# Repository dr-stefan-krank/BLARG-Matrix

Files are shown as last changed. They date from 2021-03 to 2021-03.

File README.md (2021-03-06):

**BLARG-Matrix is an open analog audio matrix board to be integrated in smart home applications.**

Its purpose is to build a central multi-room audio system.
For example 4 players connected to 8 rooms in stereo mode, 8 players to 16 rooms in mono configuration or anything in between.

**Features**

- 8x16 matrix chip to route any input to one or more outputs.
- All outputs are digitally volume controlled.
- 11 unused GPIO of the ESP
- A 16 GPIO IO expander allows for control of a 16 channel relais board for switching amplifiers.
- All inputs and outputs are unbalanced line level.

Note: The board has to be equipped with a standard ESP32-DEVKIT-C.

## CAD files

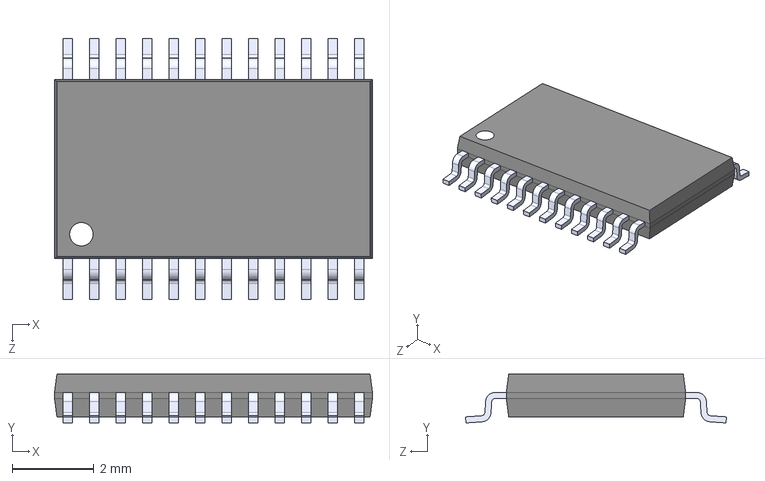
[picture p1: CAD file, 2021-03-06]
components/TCA6416APWR/TCA6416APWR.step
7.80 x 1.20 x 6.40 mm

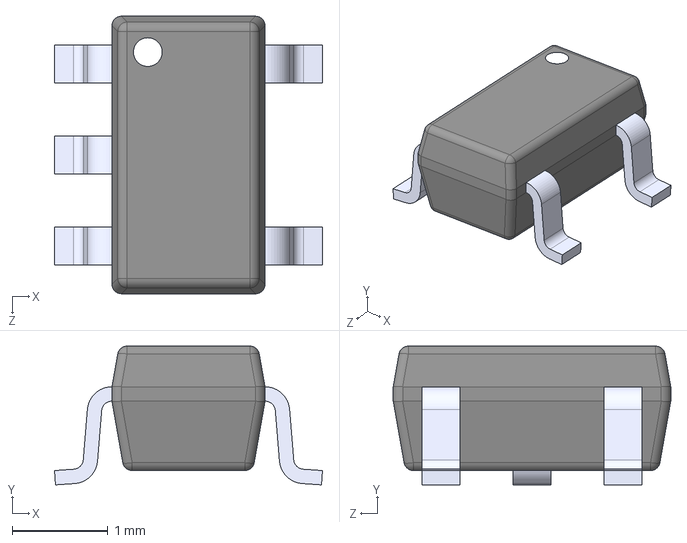
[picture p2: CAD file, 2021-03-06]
components/TPS60403DBVR/TPS60403DBVR.step
2.80 x 1.45 x 2.90 mm

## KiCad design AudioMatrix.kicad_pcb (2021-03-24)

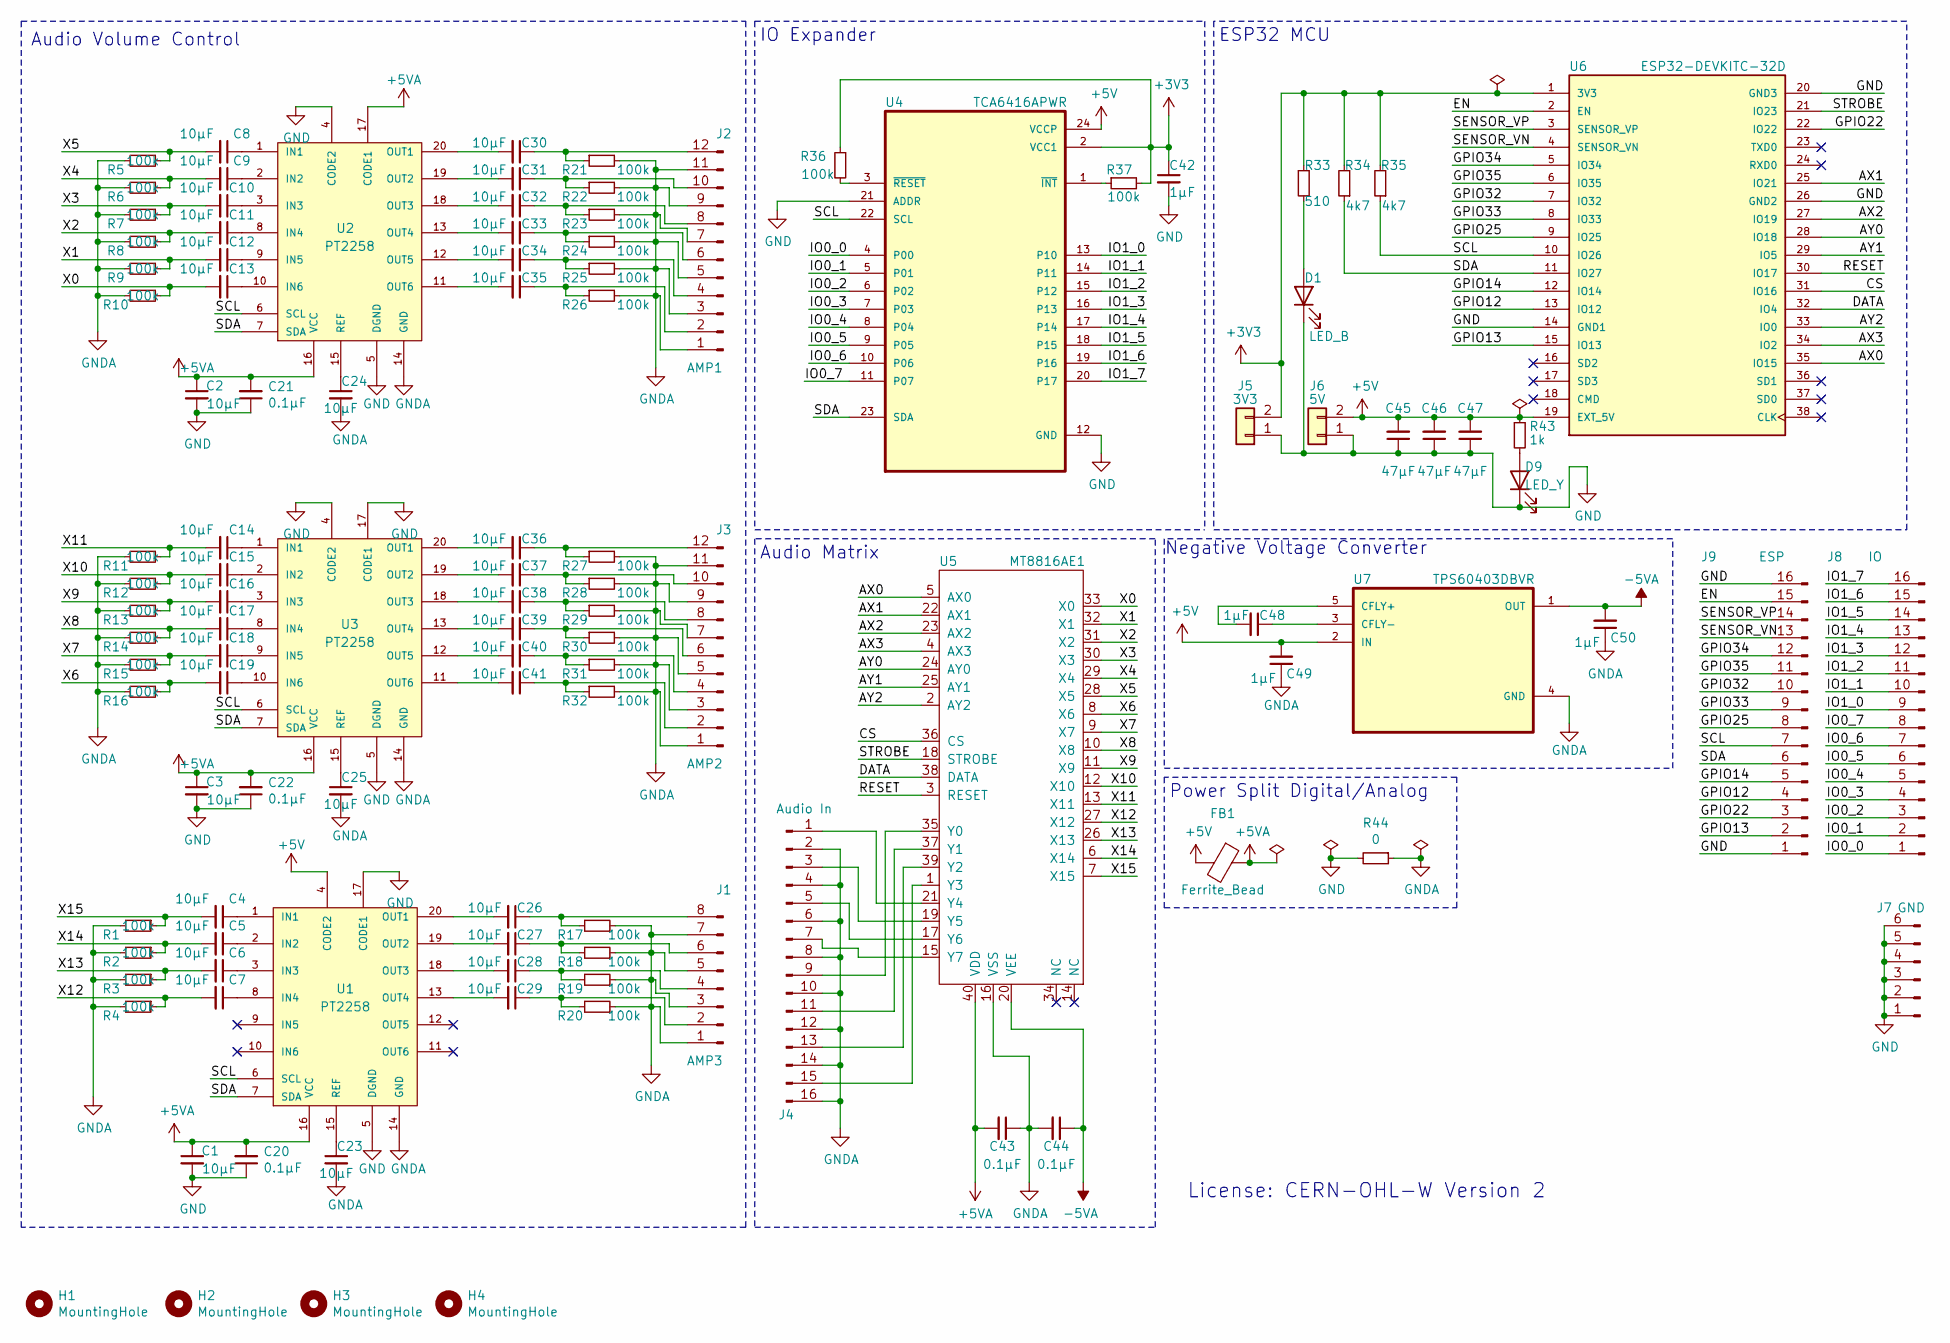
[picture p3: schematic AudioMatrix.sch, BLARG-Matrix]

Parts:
C1, C2, C3, C4, C5, C6, C7, C8, C9, C10, C11, C12, C13, C14, C15, C16, C17, C18, C19, C23, C24, C25, C26, C27, C28, C29, C31, C32, C33, C34, C35, C37, C38, C39, C40, C41: 10μF; C_0805_2012Metric
C20, C21, C22, C44: 0.1μF; C_0805_2012Metric
C30: 10μF; C_0805_2012Metric; LCSC C15850
C36: 10μF; C_0805_2012Metric; LCSC C1785
C42, C48, C49, C50: 1μF; C_0805_2012Metric; LCSC C28323
C43: 0.1μF; C_0805_2012Metric; LCSC C49678
C45, C46, C47: 47μF; C_1206_3216Metric; LCSC C96123
D1: LED_B; D_0603_1608Metric; LCSC C72041
D9: LED_Y; D_0603_1608Metric; LCSC C72038
FB1: Ferrite_Bead; L_1206_3216Metric; LCSC C94305
H1, H2, H3, H4: MountingHole; MountingHole_3.2mm_M3
J1: AMP3; PinHeader_1x08_P2.54mm_Vertical
J2: AMP1; PinHeader_1x12_P2.54mm_Vertical
J3: AMP2; PinHeader_1x12_P2.54mm_Vertical
J4: Audio In; PinHeader_1x16_P2.54mm_Vertical
J5: 3V3; PinHeader_1x02_P2.54mm_Vertical
J6: 5V; PinHeader_1x02_P2.54mm_Vertical
J7: GND; PinHeader_1x06_P2.54mm_Vertical
J8: IO; PinHeader_1x16_P2.54mm_Vertical
J9: ESP; PinHeader_1x16_P2.54mm_Vertical
R1, R2, R3, R4, R6, R7, R8, R9, R10, R11, R12, R13, R14, R15, R16, R17, R18, R19, R20, R21, R22, R23, R24, R25, R26, R27, R28, R29, R30, R31, R32, R36, R37: 100k; R_0603_1608Metric
R5: 100k; R_0603_1608Metric; LCSC C25803
R33: 510; R_0603_1608Metric; LCSC C23193
R34, R35: 4k7; R_0603_1608Metric; LCSC C23162
R43: 1k; R_0603_1608Metric; LCSC C21190
R44: 0; R_0805_2012Metric; LCSC C17477
U1, U2, U3: PT2258; SOIC-20W_7.5x12.8mm_P1.27mm; LCSC C99213
U4: TCA6416APWR; SOP65P640X120-24N; LCSC C130203
U5: MT8816AE1; DIP-40_W15.24mm_Socket
U6: ESP32-DEVKITC-32D; MODULE_ESP32-DEVKITC-32D; PARTREV 4
U7: TPS60403DBVR; SOT95P280X145-5N; LCSC C11338

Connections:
+3V3: C42.1, J5.2, R33.1, R34.2, R35.2, R36.1, R37.2, U4.2 (VCC1), U6.1 (3V3)
+5V: C45.2, C46.2, C47.2, C49.2, FB1.2, J6.2, R43.1, U1.4 (CODE2), U4.24 (VCCP), U6.19 (EXT_5V), U7.2 (IN)
+5VA: C1.1, C2.1, C3.1, C20.2, C21.2, C22.2, C43.2, FB1.1, U1.16 (VCC), U2.16 (VCC), U2.17 (CODE1), U3.16 (VCC), U5.40 (VDD)
-5VA: C44.1, C50.2, U5.20 (VEE), U7.1 (OUT)
/AX0: U5.5 (AX0), U6.35 (IO15)
/AX1: U5.22 (AX1), U6.25 (IO21)
/AX2: U5.23 (AX2), U6.27 (IO19)
/AX3: U5.4 (AX3), U6.34 (IO2)
/AY0: U5.24 (AY0), U6.28 (IO18)
/AY1: U5.25 (AY1), U6.29 (IO5)
/AY2: U5.2 (AY2), U6.33 (IO0)
/CS: U5.36 (CS), U6.31 (IO16)
/DATA: U5.38 (DATA), U6.32 (IO4)
/EN: J9.15, U6.2 (EN)
/GPIO12: J9.4, U6.13 (IO12)
/GPIO13: J9.2, U6.15 (IO13)
/GPIO14: J9.5, U6.12 (IO14)
/GPIO22: J9.3, U6.22 (IO22)
/GPIO25: J9.8, U6.9 (IO25)
/GPIO32: J9.10, U6.7 (IO32)
/GPIO33: J9.9, U6.8 (IO33)
/GPIO34: J9.12, U6.5 (IO34)
/GPIO35: J9.11, U6.6 (IO35)
/IO0_0: J8.1, U4.4 (P00)
/IO0_1: J8.2, U4.5 (P01)
/IO0_2: J8.3, U4.6 (P02)
/IO0_3: J8.4, U4.7 (P03)
/IO0_4: J8.5, U4.8 (P04)
/IO0_5: J8.6, U4.9 (P05)
/IO0_6: J8.7, U4.10 (P06)
/IO0_7: J8.8, U4.11 (P07)
/IO1_0: J8.9, U4.13 (P10)
/IO1_1: J8.10, U4.14 (P11)
/IO1_2: J8.11, U4.15 (P12)
/IO1_3: J8.12, U4.16 (P13)
/IO1_4: J8.13, U4.17 (P14)
/IO1_5: J8.14, U4.18 (P15)
/IO1_6: J8.15, U4.19 (P16)
/IO1_7: J8.16, U4.20 (P17)
/RESET: U5.3 (RESET), U6.30 (IO17)
/SCL: J9.7, R35.1, U1.6 (SCL), U2.6 (SCL), U3.6 (SCL), U4.22 (SCL), U6.10 (IO26)
/SDA: J9.6, R34.1, U1.7 (SDA), U2.7 (SDA), U3.7 (SDA), U4.23 (SDA), U6.11 (IO27)
/SENSOR_VN: J9.13, U6.4 (SENSOR_VN)
/SENSOR_VP: J9.14, U6.3 (SENSOR_VP)
/STROBE: U5.18 (STROBE), U6.21 (IO23)
/X0: C13.2, R10.1, U5.33 (X0)
/X1: C12.2, R9.1, U5.32 (X1)
/X2: C11.2, R8.1, U5.31 (X2)
/X3: C10.2, R7.1, U5.30 (X3)
/X4: C9.2, R6.1, U5.29 (X4)
/X5: C8.2, R5.1, U5.28 (X5)
/X6: C19.2, R16.1, U5.8 (X6)
/X7: C18.2, R15.1, U5.9 (X7)
/X8: C17.2, R14.1, U5.10 (X8)
/X9: C16.2, R13.1, U5.11 (X9)
/X10: C15.2, R12.1, U5.12 (X10)
/X11: C14.2, R11.1, U5.13 (X11)
/X12: C7.2, R4.1, U5.27 (X12)
/X13: C6.2, R3.1, U5.26 (X13)
/X14: C5.2, R2.1, U5.6 (X14)
/X15: C4.2, R1.1, U5.7 (X15)
GND: C1.2, C2.2, C3.2, C20.1, C21.1, C22.1, C42.2, C45.1, C46.1, C47.1, D1.1 (K), D9.1 (K), J5.1, J6.1, J7.1, J7.2, J7.3, J7.4, J7.5, J7.6, J9.1, J9.16, R44.2, U1.5 (DGND), U1.17 (CODE1), U2.4 (CODE2), U2.5 (DGND), U3.4 (CODE2), U3.5 (DGND), U3.17 (CODE1), U4.12 (GND), U4.21 (ADDR), U6.14 (GND1), U6.20 (GND3), U6.26 (GND2)
GNDA: C23.2, C24.2, C25.2, C43.1, C44.2, C49.1, C50.1, J1.1, J1.3, J1.5, J1.7, J2.1, J2.3, J2.5, J2.7, J2.9, J2.11, J3.1, J3.3, J3.5, J3.7, J3.9, J3.11, J4.2, J4.4, J4.6, J4.8, J4.10, J4.12, J4.14, J4.16, R1.2, R2.2, R3.2, R4.2, R5.2, R6.2, R7.2, R8.2, R9.2, R10.2, R11.2, R12.2, R13.2, R14.2, R15.2, R16.2, R17.2, R18.2, R19.2, R20.2, R21.2, R22.2, R23.2, R24.2, R25.2, R26.2, R27.2, R28.2, R29.2, R30.2, R31.2, R32.2, R44.1, U1.14 (GND), U2.14 (GND), U3.14 (GND), U5.16 (VSS), U7.4 (GND)
unnamed: C4.1, U1.1 (IN1)
unnamed: C5.1, U1.2 (IN2)
unnamed: C6.1, U1.3 (IN3)
unnamed: C7.1, U1.8 (IN4)
unnamed: C8.1, U2.1 (IN1)
unnamed: C9.1, U2.2 (IN2)
unnamed: C10.1, U2.3 (IN3)
unnamed: C11.1, U2.8 (IN4)
unnamed: C12.1, U2.9 (IN5)
unnamed: C13.1, U2.10 (IN6)
unnamed: C14.1, U3.1 (IN1)
unnamed: C15.1, U3.2 (IN2)
unnamed: C16.1, U3.3 (IN3)
unnamed: C17.1, U3.8 (IN4)
unnamed: C18.1, U3.9 (IN5)
unnamed: C19.1, U3.10 (IN6)
unnamed: C23.1, U1.15 (REF)
unnamed: C24.1, U2.15 (REF)
unnamed: C25.1, U3.15 (REF)
unnamed: C26.1, J1.8, R17.1
unnamed: C26.2, U1.20 (OUT1)
unnamed: C27.1, J1.6, R18.1
unnamed: C27.2, U1.19 (OUT2)
unnamed: C28.1, J1.4, R19.1
unnamed: C28.2, U1.18 (OUT3)
unnamed: C29.1, J1.2, R20.1
unnamed: C29.2, U1.13 (OUT4)
unnamed: C30.1, J2.12, R21.1
unnamed: C30.2, U2.20 (OUT1)
unnamed: C31.1, J2.10, R22.1
unnamed: C31.2, U2.19 (OUT2)
unnamed: C32.1, J2.8, R23.1
unnamed: C32.2, U2.18 (OUT3)
unnamed: C33.1, J2.6, R24.1
unnamed: C33.2, U2.13 (OUT4)
unnamed: C34.1, J2.4, R25.1
unnamed: C34.2, U2.12 (OUT5)
unnamed: C35.1, J2.2, R26.1
unnamed: C35.2, U2.11 (OUT6)
unnamed: C36.1, J3.12, R27.1
unnamed: C36.2, U3.20 (OUT1)
unnamed: C37.1, J3.10, R28.1
unnamed: C37.2, U3.19 (OUT2)
unnamed: C38.1, J3.8, R29.1
unnamed: C38.2, U3.18 (OUT3)
unnamed: C39.1, J3.6, R30.1
unnamed: C39.2, U3.13 (OUT4)
unnamed: C40.1, J3.4, R31.1
unnamed: C40.2, U3.12 (OUT5)
unnamed: C41.1, J3.2, R32.1
unnamed: C41.2, U3.11 (OUT6)
unnamed: C48.1, U7.3 (CFLY-)
unnamed: C48.2, U7.5 (CFLY+)
unnamed: D1.2 (A), R33.2
unnamed: D9.2 (A), R43.2
unnamed: J4.1, U5.21 (Y4)
unnamed: J4.3, U5.19 (Y5)
unnamed: J4.5, U5.17 (Y6)
unnamed: J4.7, U5.15 (Y7)
unnamed: J4.9, U5.35 (Y0)
unnamed: J4.11, U5.37 (Y1)
unnamed: J4.13, U5.39 (Y2)
unnamed: J4.15, U5.1 (Y3)
unnamed: R36.2, U4.3 (~RESET)
unnamed: R37.1, U4.1 (~INT)

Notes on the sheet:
Power Split Digital/Analog
Audio Matrix
IO Expander
ESP32 MCU
Audio Volume Control
Negative Voltage Converter
License: CERN-OHL-W Version 2

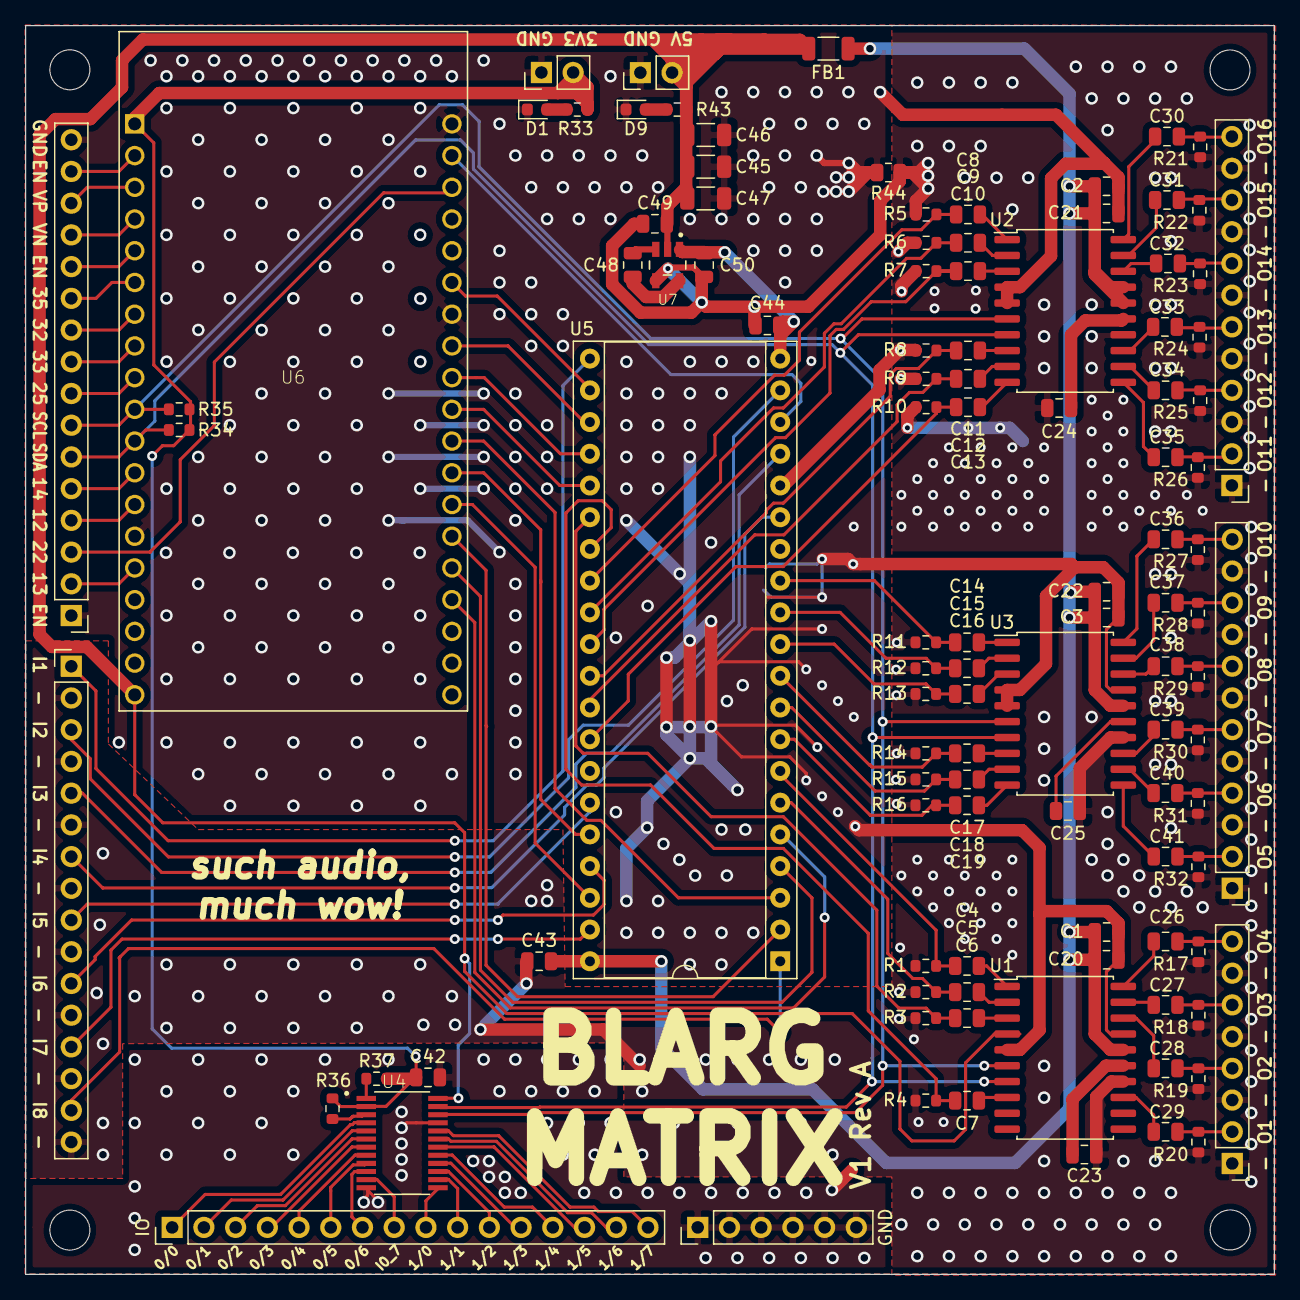
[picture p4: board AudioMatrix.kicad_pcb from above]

Board: 2 copper layers, 100.0 x 100.0 mm, 112 parts (0 on the bottom side), 128 nets.

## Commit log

2021-03-06 First version
    no reviews yet
    [AudioMatrix.kicad_pcb, AudioMatrix.sch, TPS60403DBVR.step]
2021-03-06 Removed LEDs
    [AudioMatrix.kicad_pcb, AudioMatrix.sch]
2021-03-06 Replaced IO expander
    [AudioMatrix.kicad_pcb, AudioMatrix.sch, TCA6416APWR.step]
2021-03-06 Fixed output cap design
    [AudioMatrix.kicad_pcb, AudioMatrix.sch]
2021-03-06 pcb cosmetics
    Step file for IO expander
    [AudioMatrix.kicad_pcb]
2021-03-07 Changed component placement of volume controllers
    [AudioMatrix.kicad_pcb, AudioMatrix.sch]
2021-03-07 Net labeling and cleanup
    [AudioMatrix.kicad_pcb, AudioMatrix.sch]
